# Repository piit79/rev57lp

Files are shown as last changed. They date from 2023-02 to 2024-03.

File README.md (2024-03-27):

# Rev57LP

(Formerly known by no-one as Reviung-ish56 LP :)

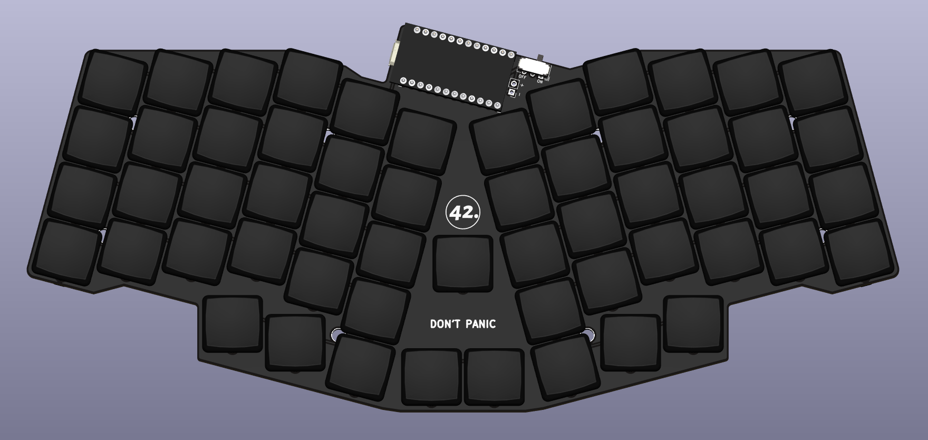
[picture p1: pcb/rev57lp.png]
Rev57LP PCB


Low-profile 57-key ergonomic keyboard inspired by Reviung41. Uses hotswap sockets for Kailh Choc V1 (PG1350) switches.

Based on [reviung-ish](https://github.com/fredbabe/reviung_ish_pcb) by oddkeeb.

Main differences from Reviung41:

* Added number row
* Added two more bottom row keys
* Added one extra middle key
* Uses hotswap sockets for Kailh Choc V1 switches with Choc spacing (18x17 mm)

Further modifications made by 42. Keebs:

* 2x 1u space key instead of a 2u with a Choc stabiliser, because nobody likes stabs
* Slightly increased angle of the sides from 13° to 15°
* Added power switch and a battery footprint
* Mounting holes changed to through holes for 3 mm diameter brass standoffs
* Dropped the middle matrix column to free up one I/O pin
* Added stacked acrylic case consisting of switch, middle and bottom plates

Full kit available for purchase at [42. Keebs](https://42keebs.eu/shop/kits/pro-micro-based/rev57lp-50-low-profile-hotswap-ergo-kit/).

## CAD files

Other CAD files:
plates/rev57lp_bottom_plate.dxf
plates/rev57lp_switch_plate.dxf
plates/rev57lp_mid_plate.dxf

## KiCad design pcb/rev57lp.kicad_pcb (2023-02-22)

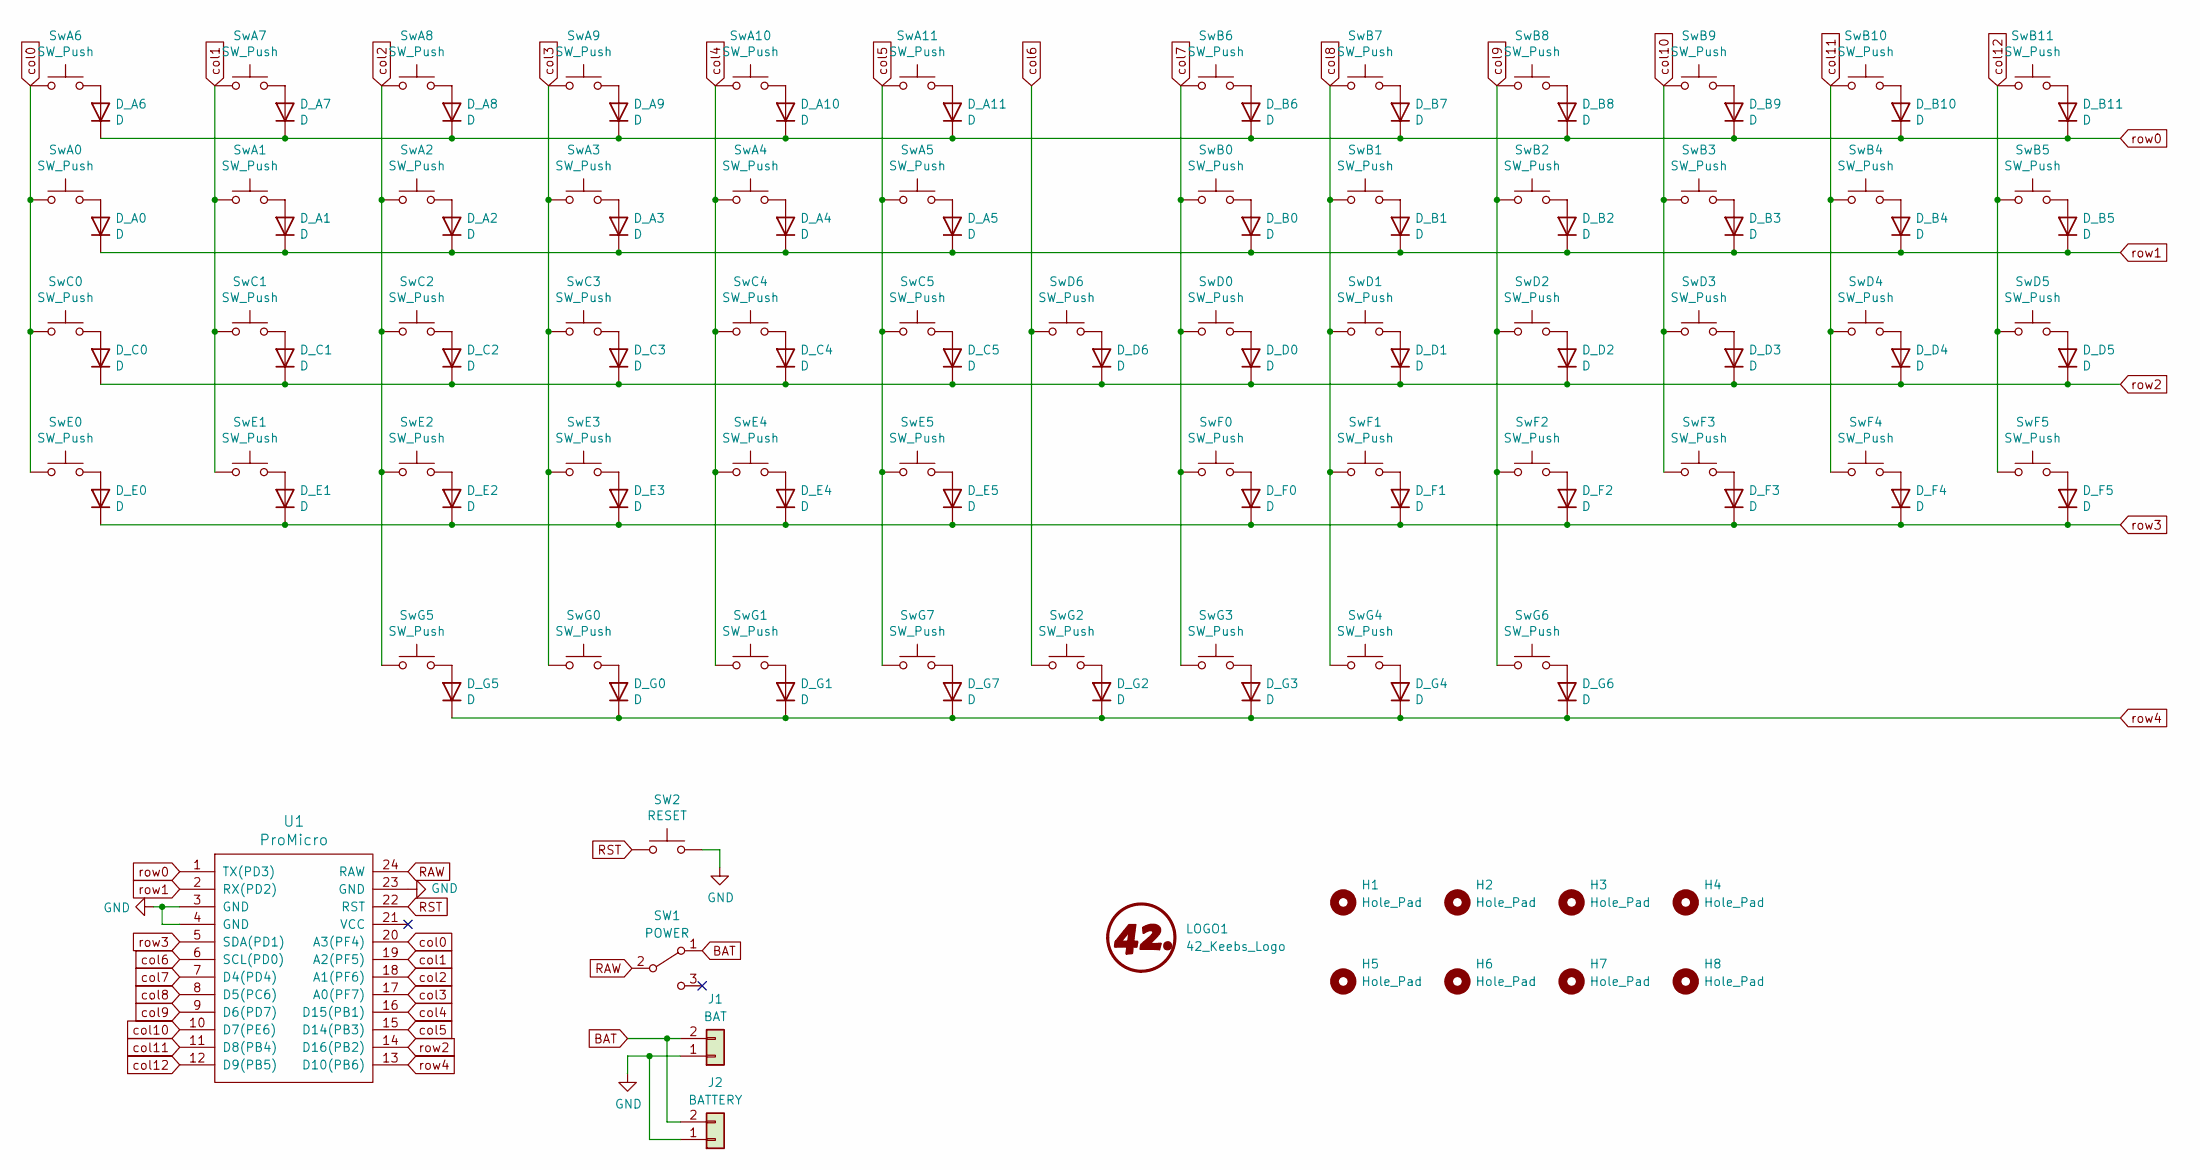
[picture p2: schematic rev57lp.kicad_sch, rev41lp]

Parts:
D_A0, D_A1, D_A2, D_A3, D_A4, D_A5, D_A6, D_A7, D_A8, D_A9, D_A10, D_A11: D; Diode_SOD123_dual_sided
D_B0, D_B1, D_B2, D_B3, D_B4, D_B5, D_B6, D_B7, D_B8, D_B9, D_B10, D_B11: D; Diode_SOD123_dual_sided
D_C0, D_C1, D_C2, D_C3, D_C4, D_C5: D; Diode_SOD123_dual_sided
D_D0, D_D1, D_D2, D_D3, D_D4, D_D5, D_D6: D; Diode_SOD123_dual_sided
D_E0, D_E1, D_E2, D_E3, D_E4, D_E5: D; Diode_SOD123_dual_sided
D_F0, D_F1, D_F2, D_F3, D_F4, D_F5: D; Diode_SOD123_dual_sided
D_G0, D_G1, D_G2, D_G3, D_G4, D_G5, D_G6, D_G7: D; Diode_SOD123_dual_sided
H1, H2, H3, H4, H5, H6, H7, H8: Hole_Pad; MountingHole_2.2mm_M2_ISO7380_Pad
J1: BAT; PinHeader_1x02_P2.54mm_Vertical
J2: BATTERY; JST_PH_S2B-PH-K_1x02_P2.00mm_Horizontal
LOGO1: 42_Keebs_Logo; 42Keebs-icon-10mm-Mask
SW1: POWER; SW_CuK_JS202011AQN_DPDT_Angled
SW2: RESET; SW_SPST_TL3342
SwA0, SwA1, SwA2, SwA3, SwA4, SwA5, SwA6, SwA7, SwA8, SwA9, SwA10, SwA11: SW_Push; Kailh_socket_PG1350_1u_sw_cap
SwB0, SwB1, SwB2, SwB3, SwB4, SwB5, SwB6, SwB7, SwB8, SwB9, SwB10, SwB11: SW_Push; Kailh_socket_PG1350_1u_sw_cap
SwC0, SwC1, SwC2, SwC3, SwC5: SW_Push; Kailh_socket_PG1350_1u_sw_cap
SwC4: SW_Push; Kailh_socket_PG1350_1u_sw_cap_home
SwD0, SwD2, SwD3, SwD4, SwD5, SwD6: SW_Push; Kailh_socket_PG1350_1u_sw_cap
SwD1: SW_Push; Kailh_socket_PG1350_1u_sw_cap_home
SwE0, SwE1, SwE2, SwE3, SwE4, SwE5: SW_Push; Kailh_socket_PG1350_1u_sw_cap
SwF0, SwF1, SwF2, SwF3, SwF4, SwF5: SW_Push; Kailh_socket_PG1350_1u_sw_cap
SwG0, SwG1, SwG2, SwG3, SwG4, SwG5, SwG6, SwG7: SW_Push; Kailh_socket_PG1350_1u_sw_cap
U1: ProMicro; ProMicro-USB-C

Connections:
BAT: J1.2, J2.2, SW1.1 (A)
GND: J1.1, J2.1, SW2.2, U1.3 (GND), U1.4 (GND), U1.23 (GND)
unnamed: D_A0.2 (A), SwA0.2
unnamed: D_A1.2 (A), SwA1.2
unnamed: D_A2.2 (A), SwA2.2
unnamed: D_A3.2 (A), SwA3.2
unnamed: D_A4.2 (A), SwA4.2
unnamed: D_A5.2 (A), SwA5.2
unnamed: D_A6.2 (A), SwA6.2
unnamed: D_A7.2 (A), SwA7.2
unnamed: D_A8.2 (A), SwA8.2
unnamed: D_A9.2 (A), SwA9.2
unnamed: D_A10.2 (A), SwA10.2
unnamed: D_A11.2 (A), SwA11.2
unnamed: D_B0.2 (A), SwB0.2
unnamed: D_B1.2 (A), SwB1.2
unnamed: D_B2.2 (A), SwB2.2
unnamed: D_B3.2 (A), SwB3.2
unnamed: D_B4.2 (A), SwB4.2
unnamed: D_B5.2 (A), SwB5.2
unnamed: D_B6.2 (A), SwB6.2
unnamed: D_B7.2 (A), SwB7.2
unnamed: D_B8.2 (A), SwB8.2
unnamed: D_B9.2 (A), SwB9.2
unnamed: D_B10.2 (A), SwB10.2
unnamed: D_B11.2 (A), SwB11.2
unnamed: D_C0.2 (A), SwC0.2
unnamed: D_C1.2 (A), SwC1.2
unnamed: D_C2.2 (A), SwC2.2
unnamed: D_C3.2 (A), SwC3.2
unnamed: D_C4.2 (A), SwC4.2
unnamed: D_C5.2 (A), SwC5.2
unnamed: D_D0.2 (A), SwD0.2
unnamed: D_D1.2 (A), SwD1.2
unnamed: D_D2.2 (A), SwD2.2
unnamed: D_D3.2 (A), SwD3.2
unnamed: D_D4.2 (A), SwD4.2
unnamed: D_D5.2 (A), SwD5.2
unnamed: D_D6.2 (A), SwD6.2
unnamed: D_E0.2 (A), SwE0.2
unnamed: D_E1.2 (A), SwE1.2
unnamed: D_E2.2 (A), SwE2.2
unnamed: D_E3.2 (A), SwE3.2
unnamed: D_E4.2 (A), SwE4.2
unnamed: D_E5.2 (A), SwE5.2
unnamed: D_F0.2 (A), SwF0.2
unnamed: D_F1.2 (A), SwF1.2
unnamed: D_F2.2 (A), SwF2.2
unnamed: D_F3.2 (A), SwF3.2
unnamed: D_F4.2 (A), SwF4.2
unnamed: D_F5.2 (A), SwF5.2
unnamed: D_G0.2 (A), SwG0.2
unnamed: D_G1.2 (A), SwG1.2
unnamed: D_G2.2 (A), SwG2.2
unnamed: D_G3.2 (A), SwG3.2
unnamed: D_G4.2 (A), SwG4.2
unnamed: D_G5.2 (A), SwG5.2
unnamed: D_G6.2 (A), SwG6.2
unnamed: D_G7.2 (A), SwG7.2
RAW: SW1.2 (B), U1.24 (RAW)
RST: SW2.1, U1.22 (RST)
col0: SwA0.1, SwA6.1, SwC0.1, SwE0.1, U1.20 (A3(PF4))
col1: SwA1.1, SwA7.1, SwC1.1, SwE1.1, U1.19 (A2(PF5))
col2: SwA2.1, SwA8.1, SwC2.1, SwE2.1, SwG5.1, U1.18 (A1(PF6))
col3: SwA3.1, SwA9.1, SwC3.1, SwE3.1, SwG0.1, U1.17 (A0(PF7))
col4: SwA4.1, SwA10.1, SwC4.1, SwE4.1, SwG1.1, U1.16 (D15(PB1))
col5: SwA5.1, SwA11.1, SwC5.1, SwE5.1, SwG7.1, U1.15 (D14(PB3))
col6: SwD6.1, SwG2.1, U1.6 (SCL(PD0))
col7: SwB0.1, SwB6.1, SwD0.1, SwF0.1, SwG3.1, U1.7 (D4(PD4))
col8: SwB1.1, SwB7.1, SwD1.1, SwF1.1, SwG4.1, U1.8 (D5(PC6))
col9: SwB2.1, SwB8.1, SwD2.1, SwF2.1, SwG6.1, U1.9 (D6(PD7))
col10: SwB3.1, SwB9.1, SwD3.1, SwF3.1, U1.10 (D7(PE6))
col11: SwB4.1, SwB10.1, SwD4.1, SwF4.1, U1.11 (D8(PB4))
col12: SwB5.1, SwB11.1, SwD5.1, SwF5.1, U1.12 (D9(PB5))
row0: D_A6.1 (K), D_A7.1 (K), D_A8.1 (K), D_A9.1 (K), D_A10.1 (K), D_A11.1 (K), D_B6.1 (K), D_B7.1 (K), D_B8.1 (K), D_B9.1 (K), D_B10.1 (K), D_B11.1 (K), U1.1 (TX(PD3))
row1: D_A0.1 (K), D_A1.1 (K), D_A2.1 (K), D_A3.1 (K), D_A4.1 (K), D_A5.1 (K), D_B0.1 (K), D_B1.1 (K), D_B2.1 (K), D_B3.1 (K), D_B4.1 (K), D_B5.1 (K), U1.2 (RX(PD2))
row2: D_C0.1 (K), D_C1.1 (K), D_C2.1 (K), D_C3.1 (K), D_C4.1 (K), D_C5.1 (K), D_D0.1 (K), D_D1.1 (K), D_D2.1 (K), D_D3.1 (K), D_D4.1 (K), D_D5.1 (K), D_D6.1 (K), U1.14 (D16(PB2))
row3: D_E0.1 (K), D_E1.1 (K), D_E2.1 (K), D_E3.1 (K), D_E4.1 (K), D_E5.1 (K), D_F0.1 (K), D_F1.1 (K), D_F2.1 (K), D_F3.1 (K), D_F4.1 (K), D_F5.1 (K), U1.5 (SDA(PD1))
row4: D_G0.1 (K), D_G1.1 (K), D_G2.1 (K), D_G3.1 (K), D_G4.1 (K), D_G5.1 (K), D_G6.1 (K), D_G7.1 (K), U1.13 (D10(PB6))

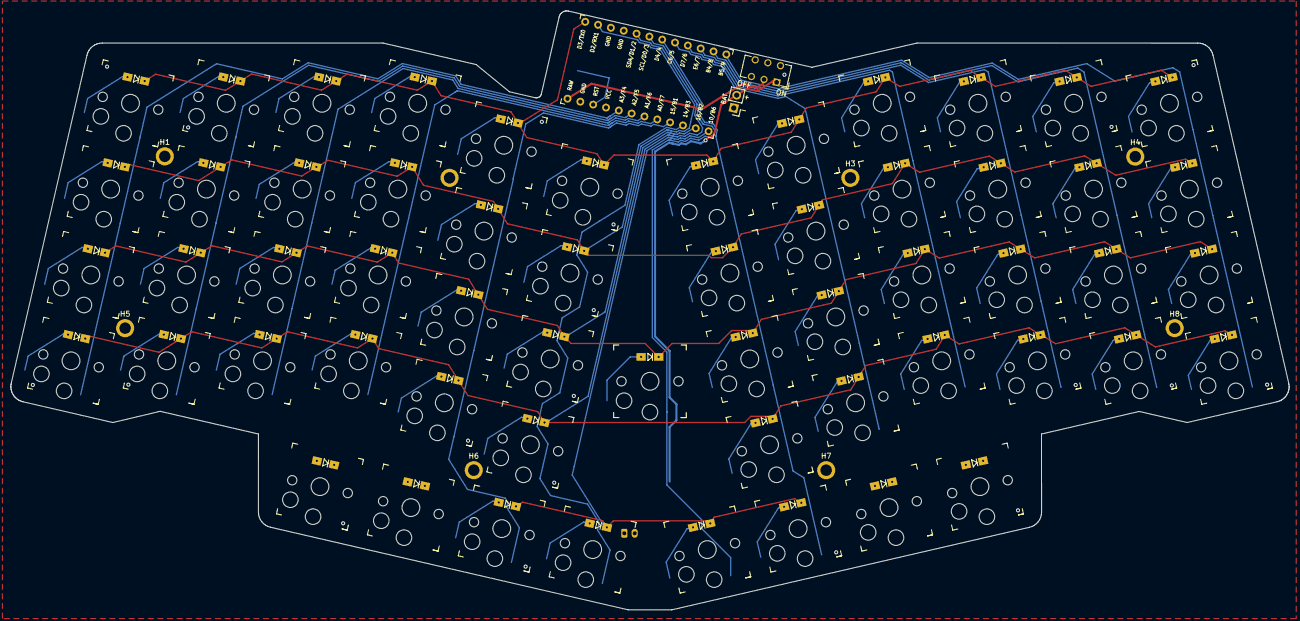
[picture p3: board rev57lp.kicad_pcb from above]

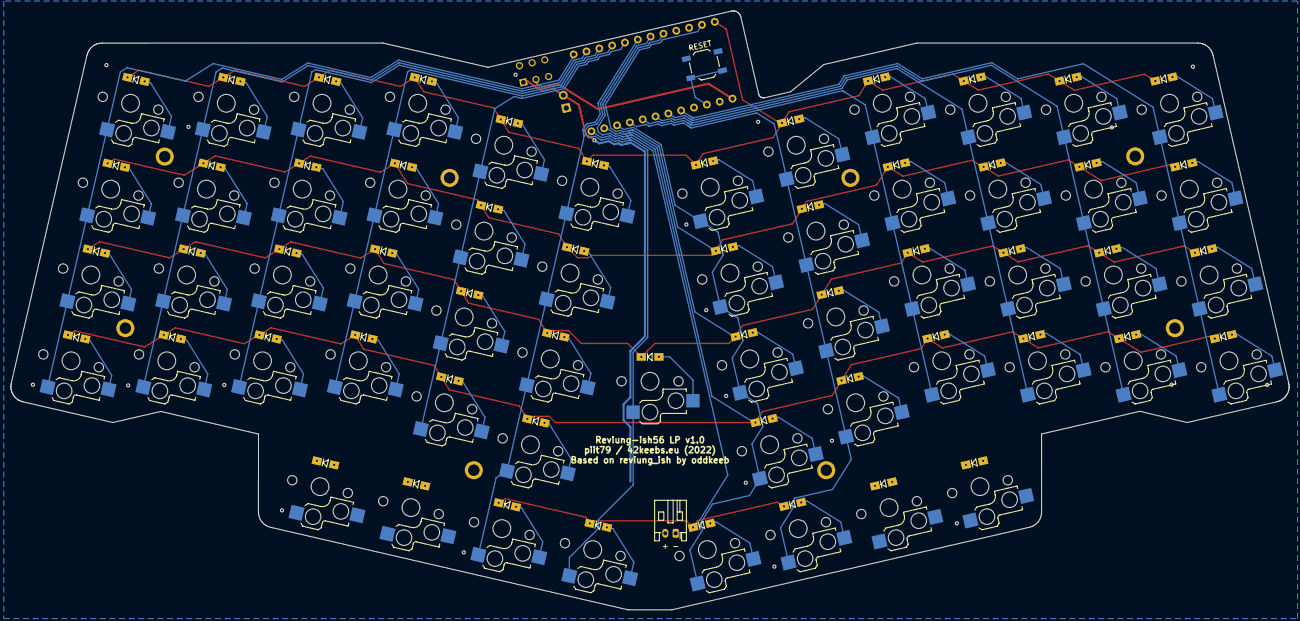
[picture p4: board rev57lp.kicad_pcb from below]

Board: 2 copper layers, 246.6 x 115.6 mm, 128 parts (59 on the bottom side), 79 nets.

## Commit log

2022-06-15 Rename the project and the main folder
    [41_1350_pcb.kicad_sch, reviung_ish_56_lp.kicad_sch]
2022-06-16 Add 42. Keebs KiCad library as a submodule
2022-06-17 Update README and add PCB image
2022-06-17 Make outline more like Reviung41; chage bottom row mods to 1u; neater col/row routing
    [reviung_ish_56_lp.kicad_sch]
2022-06-17 Make diode footprints dual-sided
    [reviung_ish_56_lp.kicad_sch]
2022-06-17 Move inner bottom mounting holes 1 row lower
2022-06-20 Move one bottom-row switch one column left in preparation for 2x1u space
    [reviung_ish_56_lp.kicad_sch]
2022-06-21 Make diode footprints dual-sided again
    [reviung_ish_56_lp.kicad_sch]
2022-06-29 Add power switch and battery connectors; update Pro Micro and some switch footprints
    [reviung_ish_56_lp.kicad_sch]
2022-06-29 Use diode footprints from 42. Keebs lib; switch to standard hole footprints
    [reviung_ish_56_lp.kicad_sch]
2022-06-29 Add battery polarity labels; fix diode reference orientation
2022-06-29 Move bottom inner holes further towards the centre; fix top inner hole not symmetric
2022-06-30 Improve some labels and a couple of traces
2022-06-30 Update README and the PCB render
2022-07-01 Improve row routing; fix missing 3D socket model on one footprint
2022-07-02 Switch to standard mounting hole footprints; bump version to 0.95
    [reviung_ish_56_lp.kicad_sch]
2022-07-05 Update 42. Keebs library (new 3D models, updated footprints)
2023-02-22 Use 1.5u space; improve outline; add power switch and battery connectors; improve routing
    [reviung_ish_56_lp.kicad_sch]
2023-02-22 WIP: switch to 2x1u space; experiment with straight bottom row
    [reviung_ish_56_lp.kicad_sch]
2023-02-22 Remove unneeded footprint library keeblib.pretty
2023-02-22 Increase the angle of the sides to 15 degrees; update README
    [rev57lp.kicad_sch]
2023-03-08 Update the 42. Keebs KiCad library
2023-03-08 Bunch of modifications and tweaks:
    * Drop the middle matrix column to free up one I/O pin
    * Use dual DPDT switch symbol to fix DRC warnings about pins with no net
    * Use standoff through holes instead of M2 mounting holes
    [rev57lp.kicad_sch]
2023-07-18 Use switch footprints with mid plte cutouts; add other mid plate cutouts
2023-07-18 Add acrylic switch, mid and bottom plate files
    [rev57lp_bottom_plate.dxf, rev57lp_mid_plate.dxf, rev57lp_switch_plate.dxf]
